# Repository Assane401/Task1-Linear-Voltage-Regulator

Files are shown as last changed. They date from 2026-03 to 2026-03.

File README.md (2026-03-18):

# Task 1 – Linear Voltage Regulator (5V)

**Author:** Assane DIENG  
**Date:** March 2026  
**Context:** EUtech Engineers – Electrical Engineering Apprenticeship

## 🎯 Objective

Design and test a 5V regulated power supply using a linear voltage regulator (L7805CV).

## 📁 Repository Structure
Task1-Linear-Voltage-Regulator/
├── KiCad/               # Schematic & PCB layout files
├── Gerbers/             # Gerber files for manufacturing
├── LTSpice/             # Simulation files
├── BOM/                 # Bill of Materials
├── Report/              # Final design report (PDF)
└── Screenshots/         # Captures of schematic, PCB, simulation

## ⚙️ Components

| Component | Reference | Value |
|---|---|---|
| Voltage Regulator | L7805CV | 5V 
| Input capacitor | C1 | 330 nF |
| Output capacitor | C2 | 100 nF |
| LED indicator | D1 | Green |
| Current limiting resistor | R1 | 

## 🔧 Tools Used

- **KiCad** – Schematic & PCB design
- **LTSpice** – Circuit simulation
- **Git / GitHub** – Version control

## 📄 Report

The full design report is available. It covers:
- Working principle of the L7805CV
- Design choices (capacitors, thermal analysis, trace width)
- Simulation results
- PCB layout decisions

## 📬 Contact
For any questions or remarks, feel free to reach out: dieng.assane98@yahoo.com

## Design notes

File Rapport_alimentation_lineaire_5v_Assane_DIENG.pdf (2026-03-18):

EUTECH ENGINEERS

ALIMENTATION 5V RÉGULÉE

Régulateur linéaire L7805CV

DIENG Assane

12/03/2026

TABLE DES MATIERES

1 Introduction

Ce rapport présente le travail réalisé dans le cadre du task 1 du stage chez Eutech Engineers.

L’objectif est la conception complète d’une alimentation régulée 5V utilisant le régulateur

linéaire L7805CV, depuis le schéma électronique jusqu’à la simulation SPICE, en passant par

le routage PCB.

Le livrable comprend :

| • Un schéma électronique complet réalisé sous KiCad
| • Un PCB monocouche routé et vérifié
| • Des fichiers Gerber prêts pour fabrication
| • Des simulations LTSpice validant le fonctionnement
| • Un rapport
| • Le tout versionné sur GitHub (Assane401)

2 | Cahier des charges
Paramètre | Valeur | Remarque
Tension d'entrée Vin | 7V à 35V | Recommandé : 8V à 12V
Tension de sortie Vout | 5,0V ± 2% | Régulée, fixe
Courant de sortie max | 1,5A absolu | 500mA en utilisation nominale
Fréquence ondulation | 100 Hz | Redressement double alternance
Protection thermique | Intégrée L7805CV | Tj_max = 125°C
Indicateur visuel | LED verte | Alimentation présente
Couche PCB | Monocouche | F. Cu uniquement
Dimensions PCB | 125mm × 45mm | Format compact
3 | Présentation du régulateur L7805CV

Le L7805CV est un régulateur de tension positive fixe 5V de la famille L78xx de

STMicroelectronics. Il intègre nativement la limitation de courant, la protection thermique et la

protection contre les courts-circuits, ce qui le rend particulièrement robuste pour les

applications industrielles [1].

Paramètre | Valeur | Condition
Tension de sortie | 5,0V ± 2% | Vin = 10V, Iout = 500mA
Courant de sortie max | 1,5A | Avec radiateur adéquat
Tension d'entrée min | 7V (dropout 2V) | Vout + Vdropout

Tension d'entrée max | 35V | Absolue
Température jonction max | 125°C | Protection thermique intégrée
Résistance thermique Rth_jc | 5°C/W | TO-220
Package | TO-220-3 | Pin1=VI, Pin2=GND, Pin3=VO
4 | Schema électronique

Le schéma suit le circuit d’application typique recommandé par la datasheet

STMicroelectronics [1], augmenté d’un circuit indicateur LED.

Réf. | Composant | Valeur | Rôle
J1 | Header 2 broches | 2,54mm | Connecteur d'entrée (Vin / GND)
C1 | Électrolytique | 100µF / 25V | Filtrage basse fréquence entrée (100Hz)
C2 | Céramique X7R | 330nF / 50V | Bypass haute fréquence (stabilité HF)
U1 | L7805CV | 5V / 1,5A | Régulateur de tension linéaire
C3 | Électrolytique | 10µF / 16V | Filtrage sortie et stabilité transitoire
R1 | Résistance 1/4W | 150Ω | Limitation courant LED
D1 | LED verte 3mm | Vf = 2V | Indicateur alimentation présente

J2 | Header 2

broches

2,54mm | Connecteur de sortie (Vout / GND)

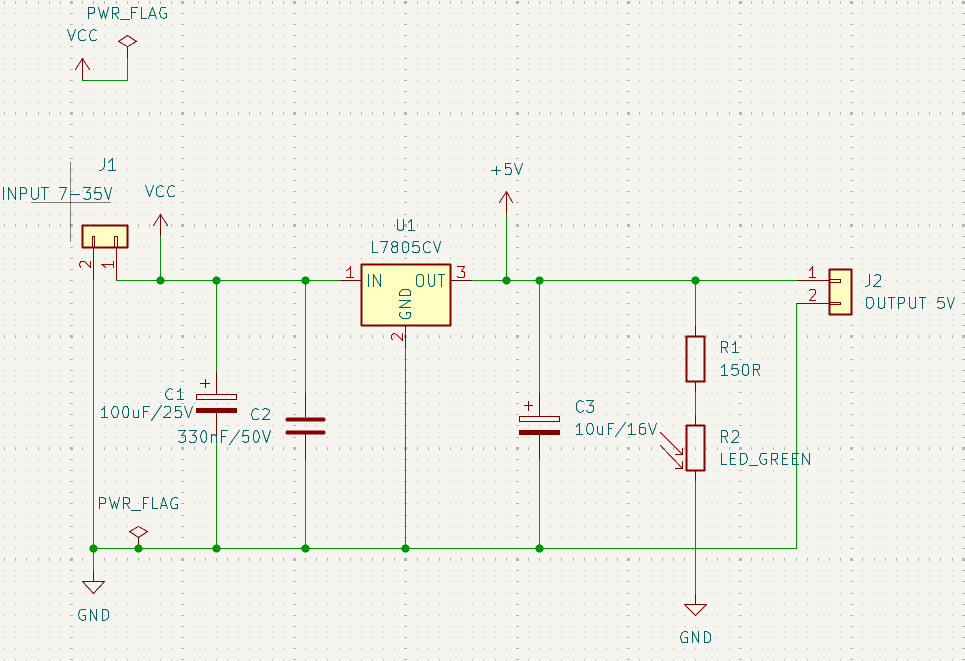
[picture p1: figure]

Figure 1: Schéma du régulateur

5 | Dimensionnement des composants
5.1 | Condensateur de filtrage entrée

C1 filtre l’ondulation basse fréquence (100 Hz) en entrée du régulateur et stocke l’énergie

nécessaire entre deux crêtes de tension.

| C1 =

Iout
2f∆V

= 2500 µF

Avec :

- Iout=0.5 A courant de charge maximum
- f =100 Hz fréquence du réseau après redressement
- ∆V= 1 V ondulation admissible en entrée

La datasheet L7805CV recommande C1 ≥ 0,33 µF. La valeur 100 µF améliore le filtrage de

l'ondulation et protège contre les chutes de tension transitoires.

Valeur commerciale choisie supérieure pour marge de sécurité : C1 = 100 µF / 25V (valeur

datasheet minimale recommandée [1])

5.2 Condensateur de bypass haute fréquence

C2 filtre les perturbations haute fréquence (parasites, switching) sur le rail d’alimentation. Il est

placé directement entre IN et GND, le plus proche possible du régulateur.

| fc =
| 1 2πRC2 − −> C2 = 15.9 nF

Objectif : atténuer les parasites à partir de 10 kHz. Et R=1 Ω

La datasheet L7805CV exige C2 ≥ 100 nF en entrée pour la stabilité. La valeur 330 nF est

recommandée pour éliminer les oscillations HF.

Valeur commerciale choisie supérieure pour marge : C2 = 330 nF / 50V

5.3 Condensateur de filtrage sortie

C3 améliore la stabilité du régulateur en sortie et filtre l’ondulation résiduelle. Il détermine la

réponse transitoire lors d’échelons en charge.

∆Vout =

Iout∆t
C3

− −> C3 = 10 µF

Avec :

- Iout=0.5 A courant d’échelon
- ∆t= 1µs temps de réponse du régulateur
- ∆Vout ≤ 50 mV chute admissible

5.4 Résistance de limitation LED

R1 limite le courant traversant la LED D1 afin de la protéger contre la destruction par

surintensité, tout en assurant un éclairage satisfaisant.

| R1 = Vout − vf
If

− −> R1 = 150 Ω

Avec :

- Vout= 5 V tension de sortie régulée
- vf=2 V tension directe LED
- If=20 mA courant nominal LED

5.5 Calcul thermique du régulateur U1

Puissance dissipée

| Pd = (Vin − Vout)Iout
| Pd = (12 − 5) ∗ 0.5 = 3.5 W

Température de jonction sans radiateur

| Tj = Ta + Rtℎ_ja ∗ Pd

Avec Rth_ja = 50°C/W (TO-220 sans radiateur) : Tj = 200 °C

Nous avons remarqué que Tj = 200°C > Tj_max = 125°C, donc un radiateur est obligatoire.

5.5.1 Température de jonction avec radiateur SK129

Tj = Ta + (Rtℎ_jc + Rtℎ_ℎs) ∗ Pd

Avec :

- Rth_jc = 5°C/W, jonction-boîtier L7805CV
- Rth_hs = 3,8°C/W, radiateur Fischer SK129

Tj = 25 + (5 + 3,8) × 3,5

Tj = 25 + 8,8 × 3,5 = 25 + 30,8 = 55,8°C

Tj = 55,8°C < 125°C → Fonctionnement sûr avec SK129

5.6 | Tableau de synthèse des composants
Réf. | Valeur | Formule | Résultat calcul | Statut
C1 | 100 µF | Iout C1 = 2f∆V | 2 500 µF min → 100 µF datasheet | Recommandé datasheet
C2 | 330 nF | fc = 1 2πRC2 | 15,9 nF min → 330 nF retenu | Stabilité HF assurée
C3 | 10 µF | Iout∆t ∆Vout = C3 | 10 µF pour ΔV ≤ 50 mV | Simulation : 130 mV
R1 | 150 Ω | Vout − vf R1 = If | 150 Ω | P = 60 mW < 250 mW
D1 | LED verte | Vf = 2V, If = 20mA | 20 mA | Éclairage nominal
U1 | L7805CV | Tj = Ta + (Rtℎ_jc + Rtℎ_ℎs) ∗ Pd | Tj = 55,8°C avec SK129 | < 125°C — Radiateur requis
6 | Simulation LTspice

Le L7805CV n'ayant pas de modèle SPICE officiel fourni par STMicroelectronics, le modèle

LT1085-5 d'Analog Devices a été utilisé comme équivalent fonctionnel. Les caractéristiques

électriques sont très proches (Vout = 5V fixe, même famille de régulateurs linéaires), avec un dropout légèrement meilleur (1,5V vs 2V) mais un comportement identique à la fréquence de

travail.

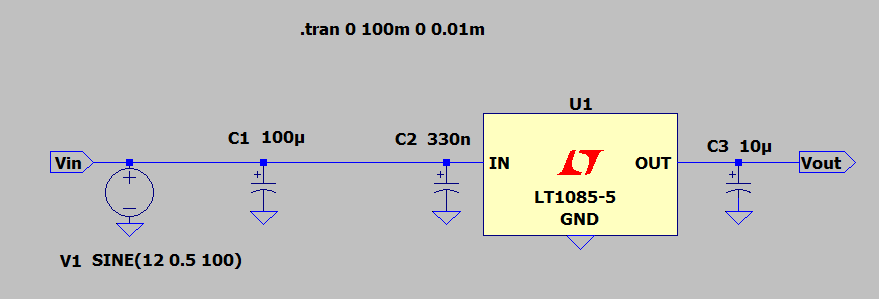
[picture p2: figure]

Figure 2: schéma sous LTspice

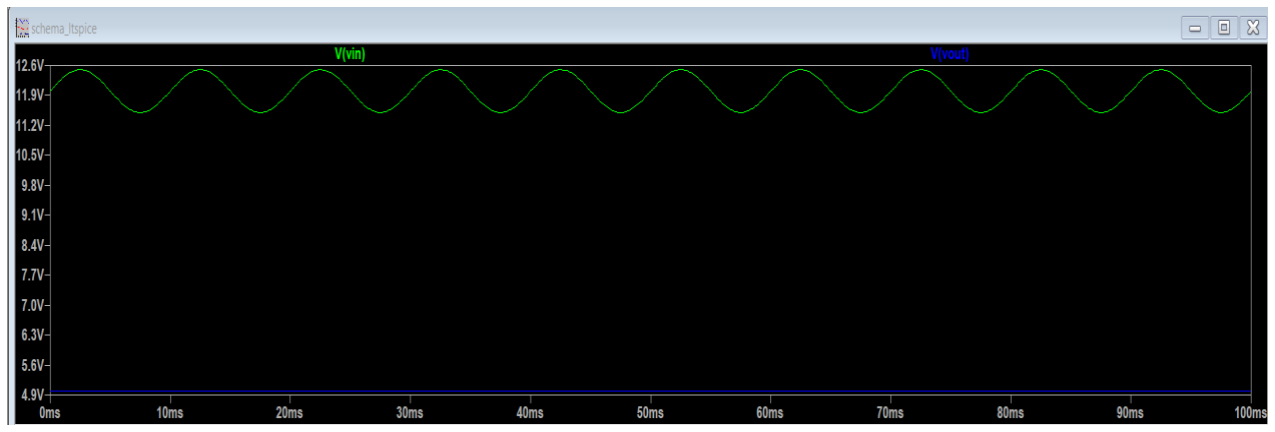
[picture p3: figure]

Figure 3: Résultat de simulation sans charge

La simulation valide le bon fonctionnement du régulateur, quelle que soit la valeur de la

tension d’entrée entre 7 et 35 V, la tension de sortie est toujours régulée à 5 volts.

6.1 Réponse en charge

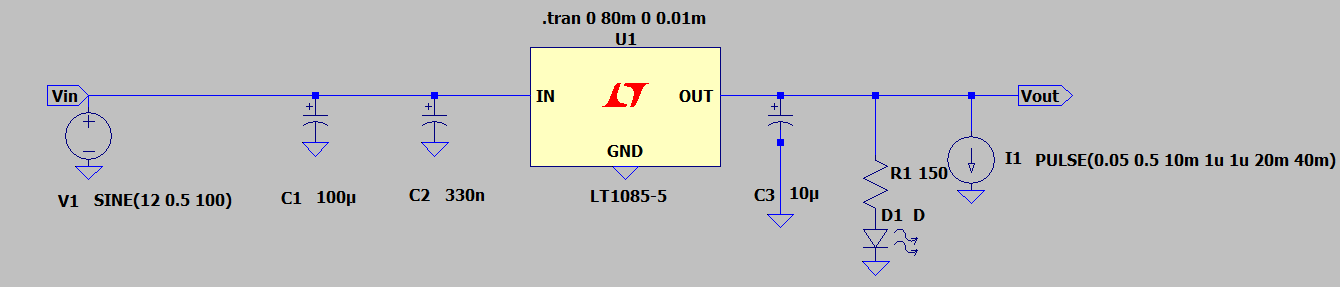
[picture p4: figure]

Figure 4 : Schéma avec charge sous LTspice

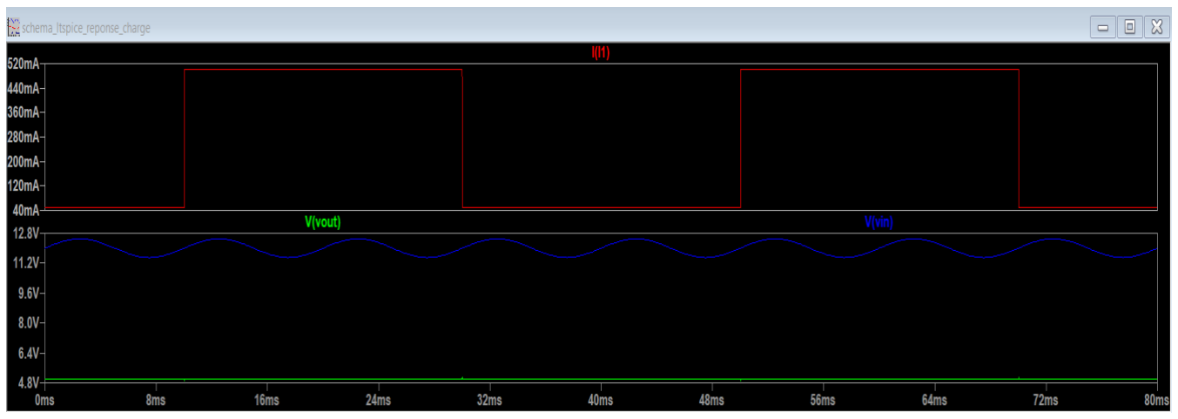
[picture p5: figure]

Figure 5 : Résultat de simulation avec charge

Le régulateur est parfaitement stable la tension de sortie est de 5 V, malgré un échelon de

charge brutal 50 mA à 480 mA et une ondulation d’entrée de 3.2 V.

7 Conclusion

Ce Task 1 a permis de réaliser la conception complète d'une alimentation régulée 5V autour

du régulateur L7805CV de STMicroelectronics. L'ensemble des étapes, schéma électronique,

routage PCB, simulation SPICE et justification des composants a été mené à terme avec

succès.

Les simulations LTSpice confirment la validité de la conception : la tension de sortie est

régulée à 5,003V (±0,006%), l'ondulation résiduelle est inférieure à 0,3mV, et la réponse en

charge montre une bonne dynamique de la tension régulée aussi.

L'analyse thermique démontre qu'un radiateur Fischer SK129 est indispensable pour maintenir

la température de jonction à 55,8°C sous une charge de 500mA avec Vin = 12V, bien en

dessous de la limite absolue de 125°C.

L'ensemble des fichiers est disponible sur GitHub (Assane401) sous le tag v1.0-submit, prêt

pour revue et fabrication.

8 Bibliographie

[1] STMicroelectronics « Datasheet officielle L7805CV ». En ligne :

https://www.st.com/resource/en/datasheet/l78.pdf

TABLES DES ILLUSTRATIONS

9 Annexe

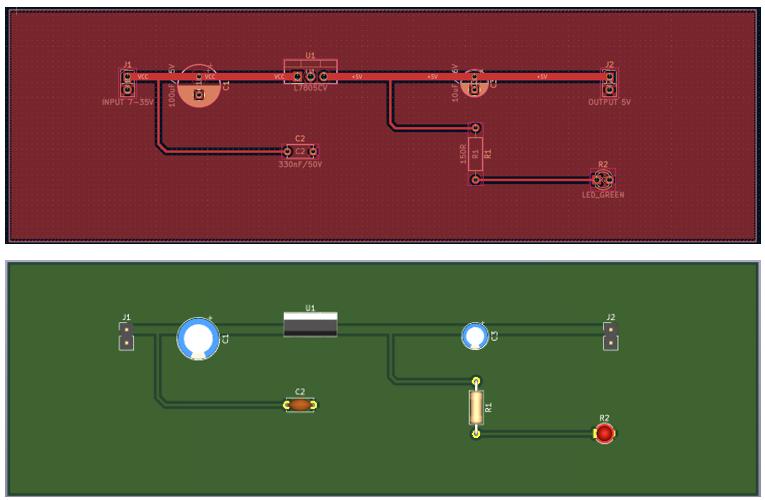
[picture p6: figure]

Annexe 1: PCB sous KiCad

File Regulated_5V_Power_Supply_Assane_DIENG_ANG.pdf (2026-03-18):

EUTECH ENGINEERS

REGULATED 5V POWER SUPPLY

L7805CV Linear Regulator

DIENG Assane

12/03/2026

TABLE OF CONTENTS

1 Introduction

This report presents the work carried out as part of Task 1 of the internship at

STMicroelectronics. The objective is the complete design of a 5V regulated power supply using

the L7805CV linear regulator, from the circuit diagram through PCB routing to SPICE

simulation.

The deliverable includes:

| • A complete electronic schematic created in KiCad
| • A routed and verified single-layer PCB
| • Gerber files ready for manufacturing
| • LTSpice simulations validating operation
| • A report
| • All versioned on GitHub (Assane401)

2 | Specifications
Parameter | Value | Note
Input voltage Vin | 7V to 35V | Recommended: 8V to 12V
Output voltage Vout | 5.0V ± 2% | Regulated, fixed
Max. output current | 1.5A absolute | 500mA at rated load
Ripple frequency | 100 Hz | Full-wave rectification
Thermal protection | Integrated L7805CV | Tj_max = 125°C
Visual indicator | Green LED | Power supply present
PCB layer | Single-layer | Copper only
PCB dimensions | 125mm × 45mm | Compact format
3 | Overview of the L7805CV Regulator

The L7805CV is a 5V fixed positive voltage regulator from STMicroelectronics’ L78xx family.

It natively integrates current limiting, thermal protection, and short-circuit protection, making

it particularly robust for industrial applications [1].

Parameter | Value | Condition
Output voltage | 5.0V ± 2% | Vin = 10V, Iout = 500mA
Max. output current | 1.5A | With adequate heat sink
Min. input voltage | 7V (2V dropout) | Vout + Vdropout

Max input voltage | 35V | Absolute
Max. junction temperature | 125°C | Built-in thermal protection
Thermal resistance Rth_jc | 5°C/W | TO-220
Package | TO-220-3 | Pin1=VI, Pin2=GND, Pin3=VO
4 | Electronic Schematic

The schematic follows the typical application circuit recommended by the STMicroelectronics

datasheet [1], with the addition of an LED indicator circuit.

Ref. | Component | Value | Function
J1 | 2-pin header | 2.54 mm | Input connector (Vin / GND)
C1 | Electrolytic | 100µF / 25V | Low-frequency input filter (100 Hz)
C2 | X7R ceramic | 330nF / 50V | High-frequency bypass (HF stability)
U1 | L7805CV | 5V / 1.5A | Linear voltage regulator
C3 | Electrolytic | 10µF / 16V | Output filtering and transient stability
R1 | 1/4W resistor | 150Ω | LED current limiting
D1 | Green LED 3mm | Vf = 2V | Power indicator on
J2 | 2-pin header | 2.54 mm | Output connector (Vout / GND)


Figure 1: Regulator schematic

5 | Component sizing
5.1 | Input filter capacitor

C1 filters low-frequency ripple (100 Hz) at the regulator input and stores the energy required

between two voltage peaks.

C1 =

Iout
2f∆V

= 2500 µF

Where:

| ➢ Iout=0.5 A maximum load current ➢ f =100 Hz mains frequency after rectification ➢ ∆V= 1 V allowable ripple at the input

The L7805CV datasheet recommends C1 ≥ 0.33 µF. The 100 µF value improves ripple filtering

and protects against transient voltage drops.

Higher commercial value selected for safety margin: C1 = 100 µF / 25V (minimum

recommended datasheet value [1])

5.2 High-frequency bypass capacitor

C2 filters high-frequency disturbances (noise, switching) on the power rail. It is placed directly

between IN and GND, as close as possible to the regulator.

| fc =
| 1 2πRC2
− −> C2 = 15.9 nF

Objective: attenuate noise starting at 10 kHz. And R=1 Ω

The L7805CV datasheet requires C2 ≥ 100 nF at the input for stability. A value of 330 nF is

recommended to eliminate HF oscillations.

Commercial value chosen higher for margin: C2 = 330 nF / 50V

5.3 Output filter capacitor

C3 improves the stability of the output regulator and filters residual ripple. It determines the

transient response during load steps.

∆Vout =

Iout∆t
C3

− −> C3 = 10 µF

Where:

- Iout=0.5 A step current
- ∆t= 1 µs controller response time
- ∆Vout ≤ 50 mV allowable voltage drop

5.4 LED limiting resistor

R1 limits the current flowing through the LED D1 to protect it from destruction by overcurrent,

while ensuring satisfactory illumination.

R1 =

Vout − vf
If

− −> R1 = 150 Ω

Where:

- Vout= 5 V regulated output voltage
- vf=2 V LED forward voltage
- If= 20 mA LED rated current

5.5 Thermal calculation for regulator U1

Power dissipation

| Pd = (Vin − Vout)Iout
| Pd = (12 − 5) ∗ 0.5 = 3.5 W

Junction temperature without heat sink

| Tj = Ta + Rtℎ_ja ∗ Pd

With Rth_ja = 50°C/W (TO-220 without heat sink): Tj = 200 °C

We have noted that Tj = 200°C > Tj_max = 125°C, so a heat sink is required.

5.5.1 Junction temperature with SK129 heat sink

Tj = Ta + (Rtℎ_jc + Rtℎ_ℎs) ∗ Pd

Where:

- Rth_jc = 5°C/W, junction-housing L7805CV
- Rth_hs = 3.8°C/W, Fischer SK129 heat sink

Tj = 25 + (5 + 3.8) × 3.5

Tj = 25 + 8.8 × 3.5 = 25 + 30.8 = 55.8°C

Tj = 55.8°C < 125°C → Safe operation with SK129

5.6 | Component summary table
Ref. | Value | Formula | Calculation result | Status
C1 | 100 µF | Iout C1 = 2f∆V | 2,500 µF min → 100 µF datasheet | Recommended datasheet
C2 | 330 nF | 1 fc = 2πRC2 | 15.9 nF min → 330 nF selected | HF stability ensured
C3 | 10 µF | Iout∆t ∆Vout = C3 | 10 µF for ΔV ≤ 50 mV | Simulation: 110 mV
R1 | 150 Ω | Vout − vf R1 = If | 150 Ω | P = 60 mW < 250 mW
D1 | Green LED | Vf = 2V, If = 20mA | 20 mA | Nominal lighting
U1 | L7805CV | Tj = Ta + (Rtℎ_jc + Rtℎ_ℎs) ∗ Pd | Tj = 55.8°C with SK129 | < 125°C — Heatsink required
6 | LTspice simulation

Since the L7805CV does not have an official SPICE model provided by STMicroelectronics,

the LT1085-5 model from Analog Devices was used as a functional equivalent. The electrical

characteristics are very similar (Vout = fixed 5V, same family of linear regulators), with a

slightly better dropout voltage (1.5V vs. 2V) but identical behavior at the operating frequency.

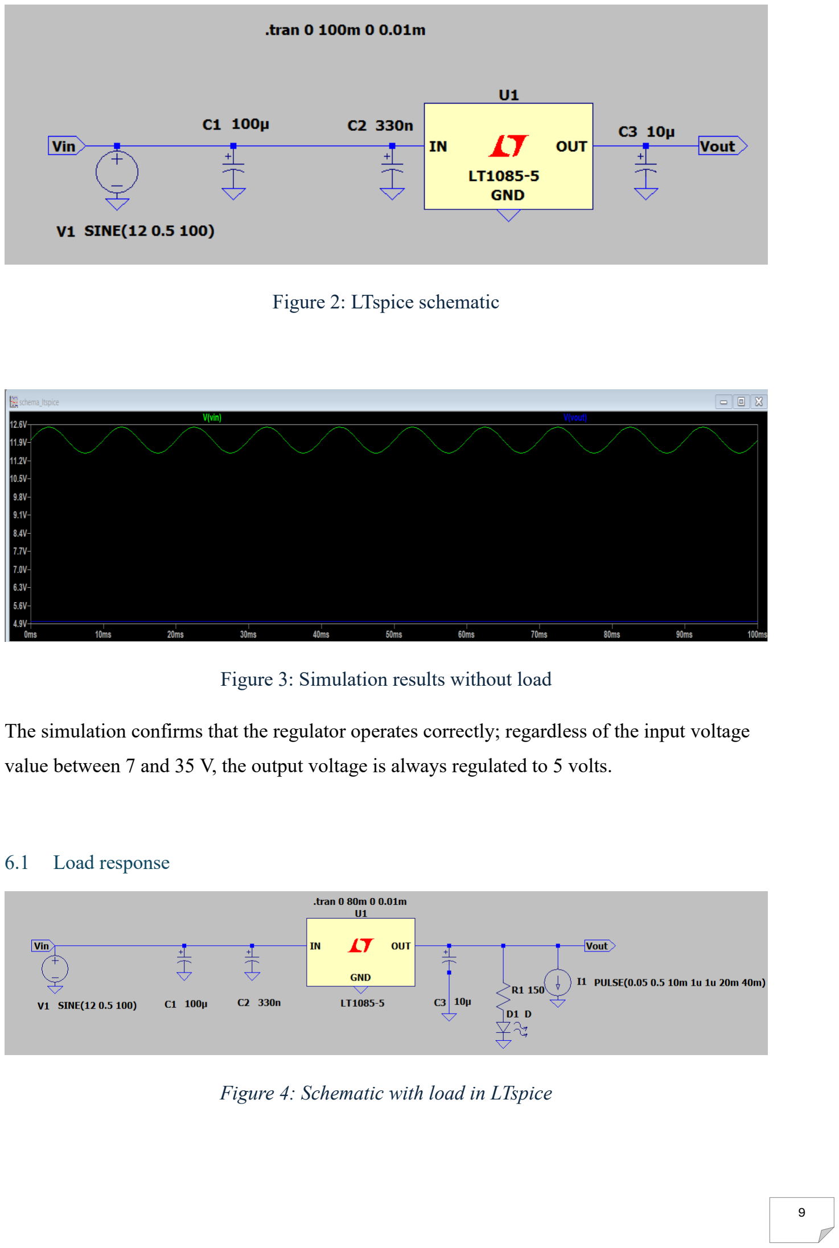
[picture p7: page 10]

Figure 2: LTspice schematic

Figure 3: Simulation results without load

The simulation confirms that the regulator operates correctly; regardless of the input voltage

value between 7 and 35 V, the output voltage is always regulated to 5 volts.

6.1 Load response

Figure 4: Schematic with load in LTspice

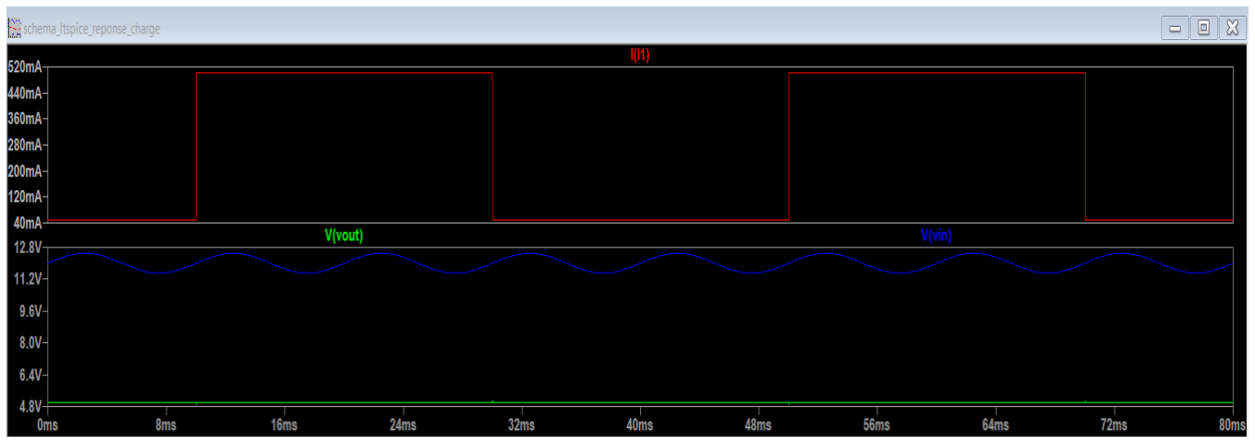
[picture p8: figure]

Figure 5: Simulation results with load

The regulator is perfectly stable; the output voltage is 5 V, despite a sudden load step from 50

mA to 480 mA and an input ripple of 3.2 V.

7 Conclusion

This Task 1 enabled the complete design of a 5V regulated power supply based on the

STMicroelectronics L7805CV regulator. All stages electronic schematic, PCB routing, SPICE

simulation, and component justification were successfully completed.

The LTSpice simulations confirm the validity of the design: the output voltage is regulated to

5.003 V (±0.006%), the residual ripple is less than 0.3 mV, and the load response also shows

good dynamics of the regulated voltage.

Thermal analysis shows that a Fischer SK129 heat sink is essential to maintain the junction

temperature at 55.8°C under a 500mA load with Vin = 12V, well below the absolute limit of

125°C.

All files are available on GitHub (Assane401) under the tag v1.0-submit, ready for review and

production.

8 References

[1] STMicroelectronics “Official L7805CV Datasheet.” Online:

https://www.st.com/resource/en/datasheet/l78.pdf

LIST OF FIGURES

9 Appendix


Appendix 1: PCB in KiCad

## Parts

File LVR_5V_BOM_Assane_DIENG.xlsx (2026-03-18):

BILL OF MATERIALS — Alimentation 5V Régulée L7805CV
Réf | Désignation | Valeur | Package / Empreinte | MPN | Fabricant | Fournisseur | Qté
J1 | Connecteur Header | 2 broches 2.54mm | PinHeader_1x02_P2.54mm_Vertical | TSW-102-07-G-S | Samtec | Mouser / Farnell | 1
C1 | Condensateur électrolytique | 100µF / 25V | CP_Radial_D8.0mm_P3.50mm | ECA-1EHG101 | Panasonic | Mouser / Farnell | 1
C2 | Condensateur céramique X7R | 330nF / 50V | C_Disc_D5.0mm_W2.5mm_P5.00mm | K334K15X7RF53L2 | Vishay | Mouser / Farnell | 1
U1 | Régulateur de tension linéaire | 5V / 1.5A | TO-220-3 Vertical | L7805CV | STMicroelectronics | Mouser / ST Store | 1
C3 | Condensateur électrolytique | 10µF / 16V | CP_Radial_D5.0mm_P2.50mm | ECA-1CGF100 | Panasonic | Mouser / Farnell | 1
R1 | Résistance carbone 1/4W | 150Ω ±5% | R_Axial_DIN0207_L6.3mm_D2.5mm_P10.00mm | CFR-25JB-52-150R | Yageo | Mouser / Farnell | 1
D1 | LED verte 3mm | Vf = 2V / If = 20mA | LED_D3.0mm | L-7113GD | Kingbright | Mouser / Farnell | 1
J2 | Connecteur Header | 2 broches 2.54mm | PinHeader_1x02_P2.54mm_Vertical | TSW-102-07-G-S | Samtec | Mouser / Farnell | 1
HS1 | Radiateur Fischer SK129 | Rth = 3.8°C/W | TO-220 / fixation vis | SK 129 25,4 STS | Fischer Elektronik | Farnell / Conrad | 1

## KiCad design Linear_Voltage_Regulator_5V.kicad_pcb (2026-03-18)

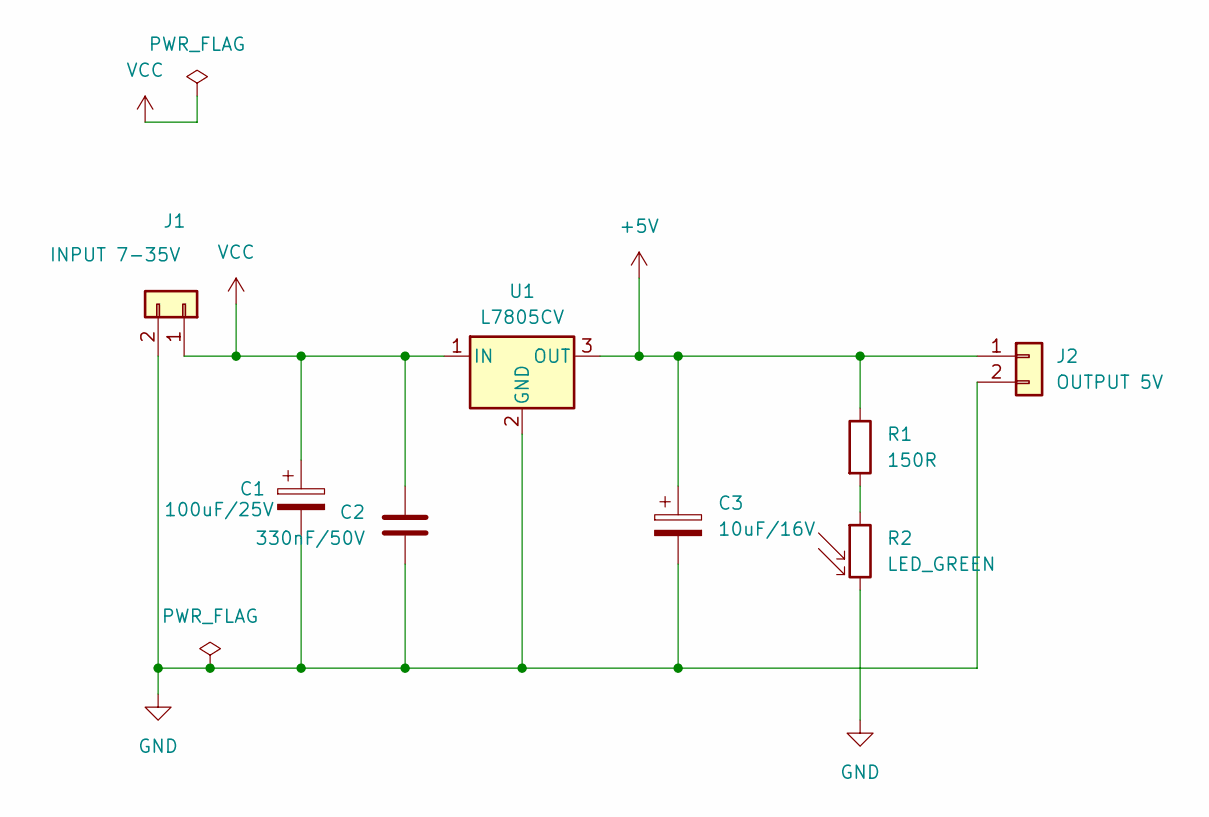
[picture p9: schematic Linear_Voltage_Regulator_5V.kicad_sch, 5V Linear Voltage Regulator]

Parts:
C1: 100uF/25V; CP_Radial_D8.0mm_P3.50mm
C2: 330nF/50V; C_Disc_D5.0mm_W2.5mm_P5.00mm
C3: 10uF/16V; CP_Radial_D5.0mm_P2.50mm
J1: INPUT 7-35V; PinHeader_1x02_P2.54mm_Vertical
J2: OUTPUT 5V; PinHeader_1x02_P2.54mm_Vertical
R1: 150R; R_Axial_DIN0207_L6.3mm_D2.5mm_P10.16mm_Horizontal
R2: LED_GREEN; LED_D3.0mm
U1: L7805CV; TO-220-3_Vertical

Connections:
+5V: C3.1, J2.1, R1.1, U1.3 (OUT)
GND: C1.2, C2.2, C3.2, J1.2, J2.2, R2.2, U1.2 (GND)
unnamed: R1.2, R2.1
VCC: C1.1, C2.1, J1.1, U1.1 (IN)

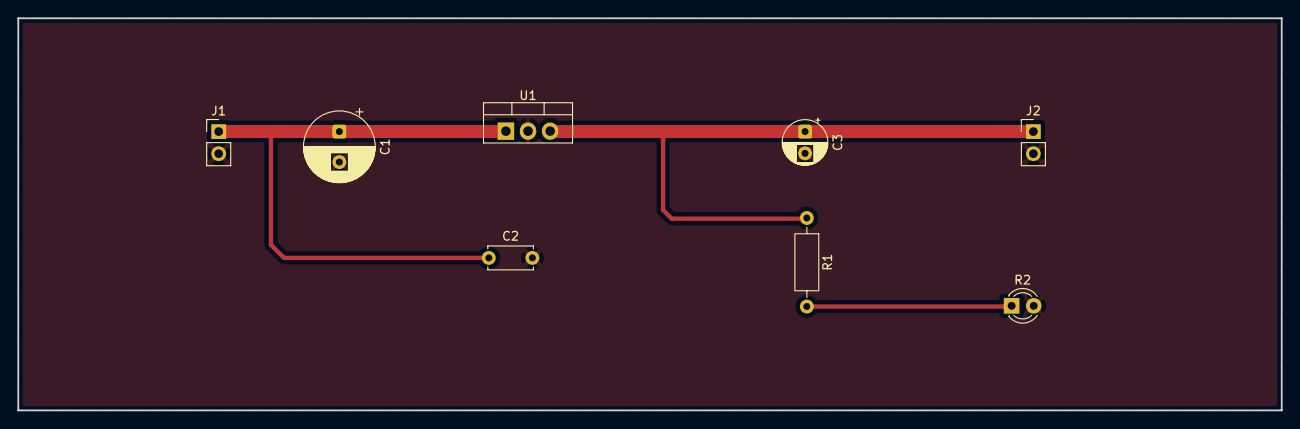
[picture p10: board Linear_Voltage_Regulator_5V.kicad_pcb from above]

Board: 2 copper layers, 145.0 x 45.0 mm, 8 parts (0 on the bottom side), 4 nets.

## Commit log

2026-03-03 Task1:L7805CV 5V complete-schematic+layout+gerbers
    [Linear_Voltage_Regulator_5V-B_Cu.gbr, Linear_Voltage_Regulator_5V-B_Mask.gbr, Linear_Voltage_Regulator_5V-B_Paste.gbr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]
2026-03-18 Task1: ajout rapport + BOM + nettoyage fichiers temporaires
    [LVR_5V_BOM_Assane_DIENG.xlsx, Linear_Voltage_Regulator_5V.kicad_pcb, Linear_Voltage_Regulator_5V.kicad_sch]
